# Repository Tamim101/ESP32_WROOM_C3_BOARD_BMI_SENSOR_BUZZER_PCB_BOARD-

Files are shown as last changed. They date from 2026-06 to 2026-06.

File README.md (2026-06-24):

3D Board View
<h2>PCB Design Screenshots</h2>

<p align="center">
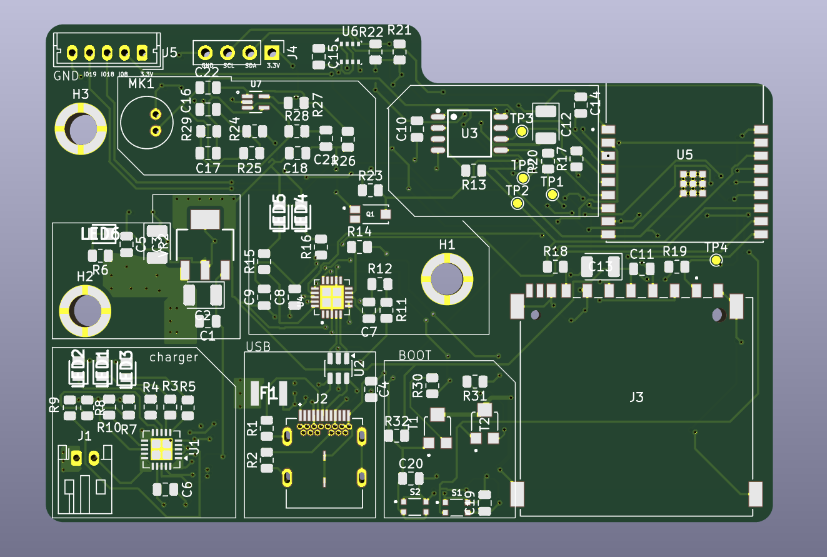
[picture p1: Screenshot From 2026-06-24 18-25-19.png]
PCB Layout in KiCad
  

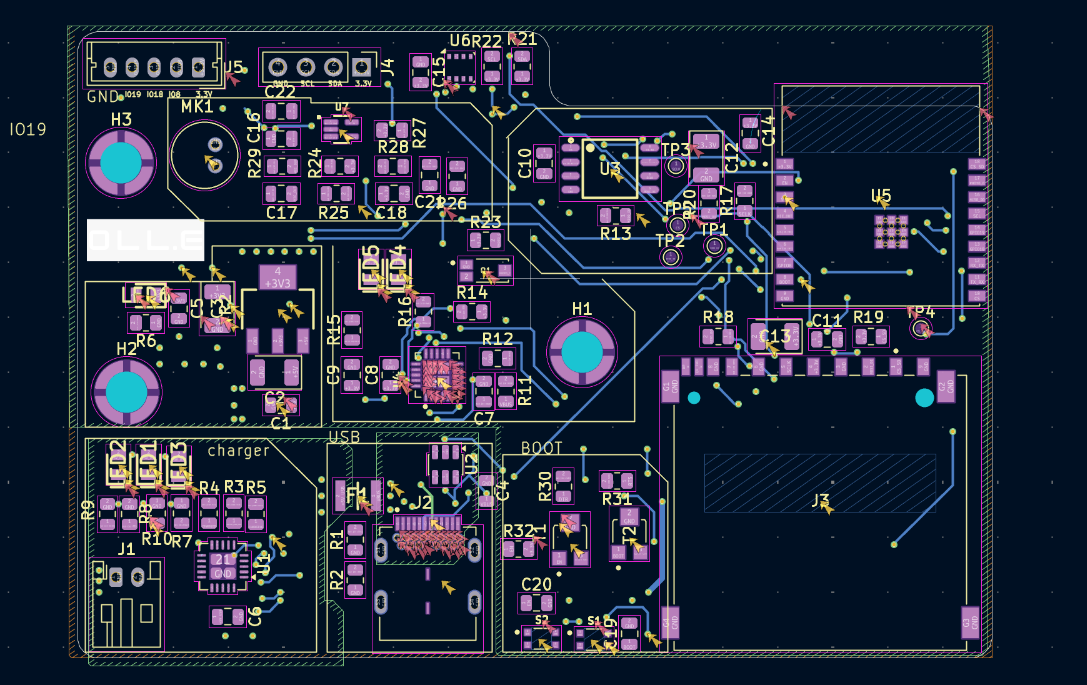
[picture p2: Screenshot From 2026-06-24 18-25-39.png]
PCB Design View in KiCad
  
</p>

Repository Structure
.
├── ESP32_project.kicad_pro
├── ESP32_project.kicad_sch
├── ESP32_project.kicad_pcb
├── ESP32_project.kicad_prl
├── Libraries/
├── ESP32_project/
├── ESP32_project-backups/
└── images/
    ├── pcb-layout.png
    └── pcb-3d-view.png
Open the Project on Ubuntu
Install KiCad 7 or a compatible newer version.
Clone or download this repository.
Open ESP32_project.kicad_pro in KiCad.
Open the schematic in Schematic Editor or the board in PCB Editor.
Design Validation Before Manufacturing

Before ordering the PCB:

Run Inspect → Electrical Rules Checker (ERC) in Schematic Editor.
Run Inspect → Design Rules Checker (DRC) in PCB Editor.
Fix all errors and confirm there are no unconnected items.
Check connector direction, component orientation, mounting holes, silkscreen, and board outline.
Open KiCad 3D Viewer to inspect component placement.
Generate Gerber and drill files, then inspect them before ordering.
Manufacturing Output

In KiCad PCB Editor:

File → Fabrication Outputs → Gerbers
File → Fabrication Outputs → Drill Files

Upload the Gerber ZIP file to a PCB manufacturer only after completing ERC, DRC, and Gerber inspection.

Initial Hardware Bring-Up

After assembly:

Check for solder bridges, missing parts, and reversed polarity.
Check resistance between power and GND before powering the board.
Use a current-limited bench power supply.
Measure power rails before connecting sensitive modules.
Upload a simple ESP32 test program.
Test the BMI sensor and buzzer separately.
License

No license has been selected yet.# ESP32_WROOM_C3_BOARD_BMI_SENSOR_BUZZER_PCB_BOARD-

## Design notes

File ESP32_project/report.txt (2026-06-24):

Change R5 field 'Datasheet' value to ''.
Change R5 field 'Description' value to ''.
Change R4 field 'Datasheet' value to ''.
Change R4 field 'Description' value to ''.
Change R3 field 'Datasheet' value to ''.
Change R3 field 'Description' value to ''.
Change U1 field 'Datasheet' value to ''.
Change U1 field 'Description' value to ''.
Change R10 field 'Datasheet' value to ''.
Change R10 field 'Description' value to ''.
Change C6 field 'Datasheet' value to ''.
Change C6 field 'Description' value to ''.
Change C2 footprint assignment from 'esp32 footprint:T491A' to 'Capacitor_Tantalum_SMD:CP_EIA-3528-21_Kemet-B'.
Change C2 field 'Datasheet' value to ''.
Change C2 field 'Description' value to ''.
Change C1 field 'Datasheet' value to ''.
Change C1 field 'Description' value to ''.
Change R1 field 'Datasheet' value to ''.
Change R1 field 'Description' value to ''.
Change R8 field 'Datasheet' value to ''.
Change R8 field 'Description' value to ''.
Change R9 field 'Datasheet' value to ''.
Change R9 field 'Description' value to ''.
Change R7 field 'Datasheet' value to ''.
Change R7 field 'Description' value to ''.
Change R6 field 'Datasheet' value to ''.
Change R6 field 'Description' value to ''.
Change C5 field 'Datasheet' value to ''.
Change C5 field 'Description' value to ''.
Change R2 field 'Datasheet' value to ''.
Change R2 field 'Description' value to ''.
Change C3 footprint assignment from 'esp32 footprint:T491A' to 'Capacitor_Tantalum_SMD:CP_EIA-3528-21_Kemet-B'.
Change C3 field 'Datasheet' value to ''.
Change C3 field 'Description' value to ''.
Change C4 field 'Datasheet' value to ''.
Change C4 field 'Description' value to ''.
Change r20 field 'Datasheet' value to ''.
Change r20 field 'Description' value to ''.
Change C14 field 'Datasheet' value to ''.
Change C14 field 'Description' value to ''.
Change R19 field 'Datasheet' value to ''.
Change R19 field 'Description' value to ''.
Change C12 footprint assignment from 'esp32 footprint:T491A' to 'Capacitor_Tantalum_SMD:CP_EIA-3528-21_Kemet-B'.
Change C12 field 'Datasheet' value to ''.
Change C12 field 'Description' value to ''.
Change R17 field 'Datasheet' value to ''.
Change R17 field 'Description' value to ''.
Change C10 field 'Datasheet' value to ''.
Change C10 field 'Description' value to ''.
Change R15 field 'Datasheet' value to ''.
Change R15 field 'Description' value to ''.
Change TP2 field 'Datasheet' value to ''.
Change TP2 field 'Description' value to ''.
Change U2 field 'Datasheet' value to ''.
Change U2 field 'Description' value to ''.
Change R16 field 'Datasheet' value to ''.
Change R16 field 'Description' value to ''.
Change C7 field 'Datasheet' value to ''.
Change C7 field 'Description' value to ''.
Change R13 field 'Datasheet' value to ''.
Change R13 field 'Description' value to ''.
Change R14 field 'Datasheet' value to ''.
Change R14 field 'Description' value to ''.
Change TP1 field 'Datasheet' value to ''.
Change TP1 field 'Description' value to ''.
Change C8 field 'Datasheet' value to ''.
Change C8 field 'Description' value to ''.
Change R11 field 'Datasheet' value to ''.
Change R11 field 'Description' value to ''.
Change R12 field 'Datasheet' value to ''.
Change R12 field 'Description' value to ''.
Change TP5 field 'Datasheet' value to ''.
Change TP5 field 'Description' value to ''.
Change TP3 field 'Datasheet' value to ''.
Change TP3 field 'Description' value to ''.
Change C13 footprint assignment from 'esp32 footprint:T491A' to 'Capacitor_Tantalum_SMD:CP_EIA-3528-21_Kemet-B'.
Change C13 field 'Datasheet' value to ''.
Change C13 field 'Description' value to ''.
Change R18 field 'Datasheet' value to ''.
Change R18 field 'Description' value to ''.
Change C11 field 'Datasheet' value to ''.
Change C11 field 'Description' value to ''.
Change TP4 field 'Datasheet' value to ''.
Change TP4 field 'Description' value to ''.
Change C9 field 'Datasheet' value to ''.
Change C9 field 'Description' value to ''.
Change C17 field 'Datasheet' value to ''.
Change C17 field 'Description' value to ''.
Change R29 field 'Datasheet' value to ''.
Change R29 field 'Description' value to ''.
Change C15 field 'Datasheet' value to ''.
Change C15 field 'Description' value to ''.
Change R25 field 'Datasheet' value to ''.
Change R25 field 'Description' value to ''.
Change R27 field 'Datasheet' value to ''.
Change R27 field 'Description' value to ''.
Change R28 field 'Datasheet' value to ''.
Change R28 field 'Description' value to ''.
Change R21 field 'Datasheet' value to ''.
Change R21 field 'Description' value to ''.
Change R22 field 'Datasheet' value to ''.
Change R22 field 'Description' value to ''.
Change R23 field 'Datasheet' value to ''.
Change R23 field 'Description' value to ''.
Change R26 field 'Datasheet' value to ''.
Change R26 field 'Description' value to ''.
Change C18 field 'Datasheet' value to ''.
Change C18 field 'Description' value to ''.
Change U6 field 'Datasheet' value to ''.
Change U6 field 'Description' value to ''.
Change R24 field 'Datasheet' value to ''.
Change R24 field 'Description' value to ''.
Change C16 field 'Datasheet' value to ''.
Change C16 field 'Description' value to ''.
Change C19 field 'Datasheet' value to ''.
Change C19 field 'Description' value to ''.
Change R30 field 'Datasheet' value to ''.
Change R30 field 'Description' value to ''.
Change J5 field 'Datasheet' value to ''.
Change J5 field 'Description' value to ''.
Change R31 field 'Datasheet' value to ''.
Change R31 field 'Description' value to ''.
Change J4 field 'Datasheet' value to ''.
Change J4 field 'Description' value to ''.
Change C20 field 'Datasheet' value to ''.
Change C20 field 'Description' value to ''.
Change R32 field 'Datasheet' value to ''.
Change R32 field 'Description' value to ''.
Change R5 field 'Datasheet' value to ''.
Change R5 field 'Description' value to ''.
Change R4 field 'Datasheet' value to ''.
Change R4 field 'Description' value to ''.
Change R3 field 'Datasheet' value to ''.
Change R3 field 'Description' value to ''.
Change U1 field 'Datasheet' value to ''.
Change U1 field 'Description' value to ''.
Change R10 field 'Datasheet' value to ''.
Change R10 field 'Description' value to ''.
Change C6 field 'Datasheet' value to ''.
Change C6 field 'Description' value to ''.
Change C2 footprint assignment from 'esp32 footprint:T491A' to 'Capacitor_Tantalum_SMD:CP_EIA-3528-21_Kemet-B'.
Change C2 field 'Datasheet' value to ''.
Change C2 field 'Description' value to ''.
Change C1 field 'Datasheet' value to ''.
Change C1 field 'Description' value to ''.
Change R1 field 'Datasheet' value to ''.
Change R1 field 'Description' value to ''.
Change R8 field 'Datasheet' value to ''.
Change R8 field 'Description' value to ''.
Change R9 field 'Datasheet' value to ''.
Change R9 field 'Description' value to ''.
Change R7 field 'Datasheet' value to ''.
Change R7 field 'Description' value to ''.
Change R6 field 'Datasheet' value to ''.
Change R6 field 'Description' value to ''.
Change C5 field 'Datasheet' value to ''.
Change C5 field 'Description' value to ''.
Change R2 field 'Datasheet' value to ''.
Change R2 field 'Description' value to ''.
Change C3 footprint assignment from 'esp32 footprint:T491A' to 'Capacitor_Tantalum_SMD:CP_EIA-3528-21_Kemet-B'.
Change C3 field 'Datasheet' value to ''.
Change C3 field 'Description' value to ''.
Change C4 field 'Datasheet' value to ''.
Change C4 field 'Description' value to ''.
Change r20 field 'Datasheet' value to ''.
Change r20 field 'Description' value to ''.
Change C14 field 'Datasheet' value to ''.
Change C14 field 'Description' value to ''.
Change R19 field 'Datasheet' value to ''.
Change R19 field 'Description' value to ''.
Change C12 footprint assignment from 'esp32 footprint:T491A' to 'Capacitor_Tantalum_SMD:CP_EIA-3528-21_Kemet-B'.
Change C12 field 'Datasheet' value to ''.
Change C12 field 'Description' value to ''.
Change R17 field 'Datasheet' value to ''.
Change R17 field 'Description' value to ''.
Change C10 field 'Datasheet' value to ''.
Change C10 field 'Description' value to ''.
Change R15 field 'Datasheet' value to ''.
Change R15 field 'Description' value to ''.
Change TP2 field 'Datasheet' value to ''.
Change TP2 field 'Description' value to ''.
Change U2 field 'Datasheet' value to ''.
Change U2 field 'Description' value to ''.
Change R16 field 'Datasheet' value to ''.
Change R16 field 'Description' value to ''.
Change C7 field 'Datasheet' value to ''.
Change C7 field 'Description' value to ''.
Change R13 field 'Datasheet' value to ''.
Change R13 field 'Description' value to ''.
Change R14 field 'Datasheet' value to ''.
Change R14 field 'Description' value to ''.
Change TP1 field 'Datasheet' value to ''.
Change TP1 field 'Description' value to ''.
Change C8 field 'Datasheet' value to ''.
Change C8 field 'Description' value to ''.
Change R11 field 'Datasheet' value to ''.
Change R11 field 'Description' value to ''.
Change R12 field 'Datasheet' value to ''.
Change R12 field 'Description' value to ''.
Change TP5 field 'Datasheet' value to ''.
Change TP5 field 'Description' value to ''.
Change TP3 field 'Datasheet' value to ''.
Change TP3 field 'Description' value to ''.
Change C13 footprint assignment from 'esp32 footprint:T491A' to 'Capacitor_Tantalum_SMD:CP_EIA-3528-21_Kemet-B'.
Change C13 field 'Datasheet' value to ''.
Change C13 field 'Description' value to ''.
Change R18 field 'Datasheet' value to ''.
Change R18 field 'Description' value to ''.
Change C11 field 'Datasheet' value to ''.
Change C11 field 'Description' value to ''.
Change TP4 field 'Datasheet' value to ''.
Change TP4 field 'Description' value to ''.
Change C9 field 'Datasheet' value to ''.
Change C9 field 'Description' value to ''.
Change C17 field 'Datasheet' value to ''.
Change C17 field 'Description' value to ''.
Change R29 field 'Datasheet' value to ''.
Change R29 field 'Description' value to ''.
Change C15 field 'Datasheet' value to ''.
Change C15 field 'Description' value to ''.
Change R25 field 'Datasheet' value to ''.
Change R25 field 'Description' value to ''.
Change R27 field 'Datasheet' value to ''.
Change R27 field 'Description' value to ''.
Change R28 field 'Datasheet' value to ''.
Change R28 field 'Description' value to ''.
Change R21 field 'Datasheet' value to ''.
Change R21 field 'Description' value to ''.
Change R22 field 'Datasheet' value to ''.
Change R22 field 'Description' value to ''.
Change R23 field 'Datasheet' value to ''.
Change R23 field 'Description' value to ''.
Change R26 field 'Datasheet' value to ''.
Change R26 field 'Description' value to ''.
Change C18 field 'Datasheet' value to ''.
Change C18 field 'Description' value to ''.
Change U6 field 'Datasheet' value to ''.
Change U6 field 'Description' value to ''.
Change R24 field 'Datasheet' value to ''.
Change R24 field 'Description' value to ''.
Change C16 field 'Datasheet' value to ''.
Change C16 field 'Description' value to ''.
Change C19 field 'Datasheet' value to ''.
Change C19 field 'Description' value to ''.
Change R30 field 'Datasheet' value to ''.
Change R30 field 'Description' value to ''.
Change J5 field 'Datasheet' value to ''.
Change J5 field 'Description' value to ''.
Change R31 field 'Datasheet' value to ''.
Change R31 field 'Description' value to ''.
Change J4 field 'Datasheet' value to ''.
Change J4 field 'Description' value to ''.
Change C20 field 'Datasheet' value to ''.
Change C20 field 'Description' value to ''.
Change R32 field 'Datasheet' value to ''.
Change R32 field 'Description' value to ''.

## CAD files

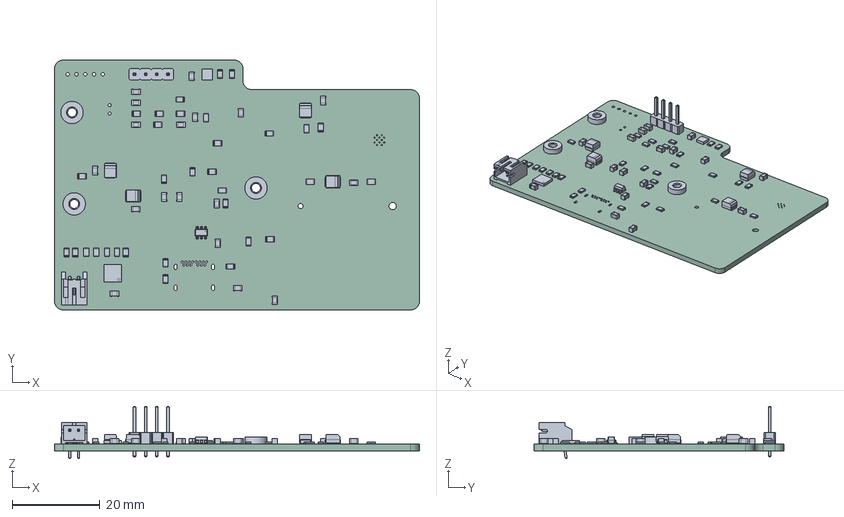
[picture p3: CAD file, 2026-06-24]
ESP32_project/ESP32_project.step
83.2 x 57.0 x 11.9 mm
C_0805_2012Metric x 18
R_0805_2012Metric x 32
CP_EIA-3528-21_Kemet-B x 4
Mounting_Wuerth_WA-SMSI-M2.5_H1.5mm_9774015151 x 3
SOT-23-6
Bosch_LGA-8_2.5x2.5mm_P0.65mm_ClockwisePinNumbering
JST_PH_S2B-PH-K_1x02_P2.00mm_Horizontal
QFN-20-1EP_4x4mm_P0.5mm_EP2.5x2.5mm
PinHeader_1x04_P2.54mm_Vertical
ESP32_project_PCB

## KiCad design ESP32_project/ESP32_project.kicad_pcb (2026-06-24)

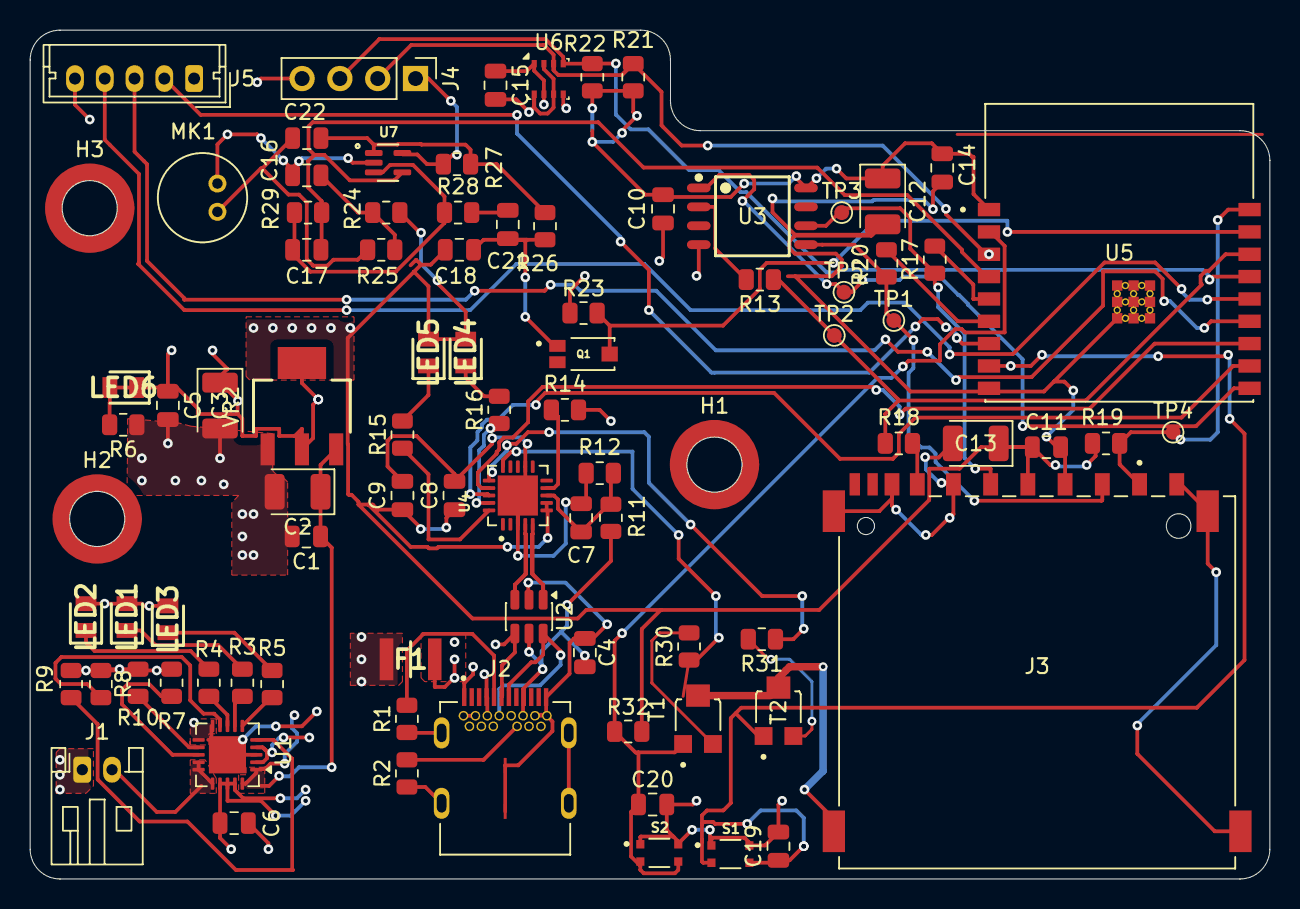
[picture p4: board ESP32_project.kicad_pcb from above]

Board: 4 copper layers, 83.2 x 57.0 mm, 88 parts (0 on the bottom side), 59 nets.

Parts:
C1, C4, C5, C9, C10, C11, C14, C15, C16, C17, C18, C19: 100nF; C_0805_2012Metric
C2, C3, C12, C13: 10uF; CP_EIA-3528-21_Kemet-B
C6, C7, C20, C21: 1uF; C_0805_2012Metric
C8: 4.7uF; C_0805_2012Metric
C22: 10n; C_0805_2012Metric
F1: 0ZCH0110AF2E; FUSC3226X100N
H1, H2, H3: hole; Mounting_Wuerth_WA-SMSI-M2.5_H1.5mm_9774015151
J1: S2B-PH-K-S(LF)(SN); JST_PH_S2B-PH-K_1x02_P2.00mm_Horizontal
J2: SS-52400-003; BELFUSE_SS-52400-002
J3: GSD090012SEU; AMPHENOL_GSD090012SEU
J4: Conn_01x04_Pin; PinHeader_1x04_P2.54mm_Vertical
J5: Conn_01x05_Pin; Molex_Micro-Latch_53253-0570_1x05_P2.00mm_Vertical
LED1, LED2, LED3, LED4, LED5, LED6: LTST-C170GKT; LEDC2012X120N
MK1: CMC-5042PF-AC; CUI_CMC-5042PF-AC
Q1: TEMT6000X01; TRANS_TEMT6000X01
R1, R2: 5.1K; R_0805_2012Metric
R3, R4, R5, R6, R15, R16: 470; R_0805_2012Metric
R7, R24, R25: 2K; R_0805_2012Metric
R8, R9, R19, R23, R28, R29, R30, R31, R32: 10K; R_0805_2012Metric
R10: 20K; R_0805_2012Metric
R11: 22.1K; R_0805_2012Metric
R12: 47.5K; R_0805_2012Metric
R13, R17, R18, R20: 50; R_0805_2012Metric
R14: 1K; R_0805_2012Metric
R21, R22: 4.7K; R_0805_2012Metric
R26, R27: 1M; R_0805_2012Metric
S1: BOOT; SW_USLPT2819DT2TR
S2: RESET; SW_USLPT2819DT2TR
T1, T2: BC817; TRIM_35WR100KLFTR
TP1: TEST MOSI; TestPoint_Pad_D1.0mm
TP2: TEST MISO; TestPoint_Pad_D1.0mm
TP3: TEST SCLK; TestPoint_Pad_D1.0mm
TP4: TEST CD; TestPoint_Pad_D1.0mm
TP5: TEST CS; TestPoint_Pad_D1.0mm
U1: MCP73871; QFN-20-1EP_4x4mm_P0.5mm_EP2.5x2.5mm
U2: USBLC6-2SC6; SOT-23-6
U3: W25Q32JVSSIQ; SOIC127P790X216-8N
U4: CP2102N-Axx-xQFN20; QFN50P400X400X100-21N
U5: ESP32-C3-WROOM-02-N4; MODULE_ESP32-C3-WROOM-02-H4
U6: BME280; Bosch_LGA-8_2.5x2.5mm_P0.65mm_ClockwisePinNumbering
U7: MAX4466EXK; SOT65P210X110-5N
VR2: LM1117MPX-3.3; VREG_LM1117MPX-3.3

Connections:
+3.3V: C8.1, C9.1, C10.1, C11.1, C12.1, C13.1, C14.1, C15.2, C18.1, J3.4 (VDD1), J4.1, J5.1, LED4.2, LED5.2, R14.1, R19.2, R21.1, R22.1, R23.1, R24.2, R27.2, R32.2, U3.8 (VCC), U4.6 (VDD), U4.7 (VREGIN), U5.1 (3V3), U6.2 (CSB), U6.6 (VDDIO), U6.8 (VDD), U7.5 (VCC)
+3V3: C3.1, C5.1, LED6.1, VR2.2 (VOUT_2), VR2.4 (VOUT_4)
+5V: C1.1, C2.1, U1.1 (OUT), U1.20 (OUT), VR2.3 (VIN)
/+5V_USB: C6.1, F1.2, LED1.2, LED2.2, LED3.2, U1.2 (VPCC), U1.4 (PROG2), U1.17 (CE), U1.18 (IN), U1.19 (IN)
/CHARGED: R4.1, U1.8 (STAT1/~LBO)
/CHARGING: R5.1, U1.6 (~PG)
/CHARGING_POWER_GOOD: R3.1, U1.7 (STAT2)
/USB_DN: J2.A7 (DN1), J2.B7 (DN2), U2.6 (I/O1)
/USB_DP: J2.A6 (DP1), J2.B6 (DP2), U2.4 (I/O2)
/VBAT: J1.2, U1.14 (V_{BAT}), U1.15 (V_{BAT}), U1.16 (V_{BAT_SENSE})
/VBUS: C4.1, F1.1, J2.A4 (VBUSA1), J2.A9 (VBUSA2), J2.B4 (VBUSB1), J2.B9 (VBUSB2), R11.1, U2.5 (VBUS)
/esp32 c3 0.2/BOOT: C19.1, S1.3, S1.4, T2.1, U5.8 (IO9)
/esp32 c3 0.2/CS: TP5.1, U3.1 (~CS), U5.10 (IO10)
/esp32 c3 0.2/CS_SD: J3.1 (CD/DAT3), R19.1, TP4.1, U5.18 (IO0)
/esp32 c3 0.2/DTR: R30.1, U4.15 (~CTS)
/esp32 c3 0.2/EN: C20.1, R32.1, S2.3, S2.4, T1.1, U5.2 (EN)
/esp32 c3 0.2/GPIO8: J5.2, U5.7 (IO8)
/esp32 c3 0.2/GPIO18: J5.3, U5.13 (IO18)
/esp32 c3 0.2/GPIO19: J5.4, U5.14 (IO19)
/esp32 c3 0.2/MIC_OUT: C17.2, R29.2, U5.4 (IO5), U7.4 (OUT)
/esp32 c3 0.2/MISO_DO: R13.1, R18.2, TP2.1, U5.16 (IO2)
/esp32 c3 0.2/MOSI_DI: J3.2 (CMD), R20.2, TP1.1, U3.5 (DI(IO0))
/esp32 c3 0.2/PHOTO_C: Q1.3, R23.2, U5.17 (IO1)
/esp32 c3 0.2/RTS: R31.1, U4.16 (~RTS)
/esp32 c3 0.2/RX_TX: U4.17 (RXD), U5.12 (TXD)
/esp32 c3 0.2/SCL: J4.3, R22.2, U5.15 (IO3), U6.4 (SCK)
/esp32 c3 0.2/SCLK: J3.5 (CLK), R17.1, TP3.1, U3.6 (CLK)
/esp32 c3 0.2/SDA: J4.2, R21.2, U5.3 (IO4), U6.3 (SDI)
/esp32 c3 0.2/TX_RX: U4.18 (TXD), U5.11 (RXD)
/esp32 c3 0.2/USB_D+: U2.3 (I/O2), U4.4 (D+)
/esp32 c3 0.2/USB_D-: U2.1 (I/O1), U4.5 (D-)
GND: C1.2, C2.2, C3.2, C4.2, C5.2, C6.2, C7.2, C8.2, C9.2, C10.2, C11.2, C12.2, C13.2, C14.2, C15.1, C16.1, C18.2, C19.2, C20.2, C21.1, J1.1, J2.A1 (GNDA1), J2.A12 (GNDA2), J2.B1 (GNDB1), J2.B12 (GNDB2), J2.G1 (GND/SHIELD), J2.G2 (GND/SHIELD), J2.G3 (GND/SHIELD), J2.G4 (GND/SHIELD), J2.S1 (GND/SHIELD), J2.S2 (GND/SHIELD), J2.S3 (GND/SHIELD), J2.S4 (GND/SHIELD), J3.3 (VSS1), J3.6 (VSS2), J3.8 (DAT1), J3.9 (DAT2), J3.G1 (SHIELD_GND), J3.G2 (SHIELD_GND), J3.G3 (SHIELD_GND), J3.G4 (SHIELD_GND), J4.4, J5.5, MK1.GND, Q1.1, R1.1, R2.1, R6.1, R7.1, R8.2, R9.2, R10.1, R12.2, R26.1, S1.1, S1.2, S2.1, S2.2, T1.2, T2.2, U1.3 (SEL), U1.10 (V_{SS}), U1.11 (V_{SS}), U1.21 (V_{SS}), U2.2 (GND), U3.4 (GND), U4.3 (GND), U4.12 (GND), U4.21 (GND), U5.9 (GND), U5.19 (GND), U5.20 (GND), U5.21 (GND), U5.22 (GND), U5.23 (GND), U5.24 (GND), U5.25 (GND), U5.26 (GND), U5.27 (GND), U5.28 (GND), U5.29 (GND), U5.30 (GND), U5.31 (GND), U5.32 (GND), U5.33 (GND), U5.34 (GND), U5.35 (GND), U5.36 (GND), U5.37 (GND), U5.38 (GND), U5.39 (GND), U6.1 (GND), U6.5 (SDO), U6.7 (GND), U7.2 (GND), VR2.1 (GND)
unnamed: C16.2, R24.1, R25.2
unnamed: C21.2, R28.1
unnamed: C22.2, MK1.OUT, R25.1
unnamed: J2.A5 (CC1), R1.2
unnamed: J2.B5 (CC2), R2.2
unnamed: J3.7 (DAT0), R18.1
unnamed: LED1.1, R3.2
unnamed: LED2.1, R4.2
unnamed: LED3.1, R5.2
unnamed: LED4.1, R16.2
unnamed: LED5.1, R15.2
unnamed: LED6.2, R6.2
unnamed: R30.2, T1.3
unnamed: R31.2, T2.3
unnamed: R7.2, U1.13 (PROG1)
unnamed: R10.2, U1.12 (PROG3)
unnamed: R9.1, U1.5 (THERM)
unnamed: R8.1, U1.9 (~TE)
unnamed: R13.2, U3.2 (DO(IO1))
unnamed: C7.1, R11.2, R12.1, U4.8 (VBUS)
unnamed: R14.2, U4.9 (~RST)
unnamed: R16.1, U4.19 (~RXT/GPIO.3)
unnamed: R15.1, U4.20 (~TXT/GPIO.2)
unnamed: R17.2, U5.5 (IO6)
unnamed: R20.1, U5.6 (IO7)
unnamed: C22.1, R26.2, R27.1, U7.1 (IN+)
unnamed: C17.1, R28.2, R29.1, U7.3 (IN-)

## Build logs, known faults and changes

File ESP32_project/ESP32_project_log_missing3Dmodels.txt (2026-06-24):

[('LED2', '/home/tamim-khan/pcb/ESP32_project/LTST-C170KRKT.stp'), ('F1', '/home/tamim-khan/pcb/ESP32_project/0ZCH0110AF2E.stp'), ('LED4', '/home/tamim-khan/pcb/ESP32_project/LTST-C170KRKT.stp'), ('LED3', '/home/tamim-khan/pcb/ESP32_project/LTST-C170KRKT.stp'), ('J5', '/usr/share/kicad/3dmodels/Connector_Molex.3dshapes/Molex_Micro-Latch_53253-0570_1x05_P2.00mm_Vertical.step'), ('LED6', '/home/tamim-khan/pcb/ESP32_project/LTST-C170KRKT.stp'), ('LED1', '/home/tamim-khan/pcb/ESP32_project/LTST-C170KRKT.stp'), ('LED5', '/home/tamim-khan/pcb/ESP32_project/LTST-C170KRKT.stp')]

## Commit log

2026-06-24 update pcb
    [ESP32_project-B_Cu.gbr, ESP32_project-B_Mask.gbr, ESP32_project-B_Paste.gbr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]
2026-06-24 update pcb Image
2026-06-24 Enhance README with PCB design and usage instructions
    Added detailed PCB design information, repository structure, and manufacturing instructions.
